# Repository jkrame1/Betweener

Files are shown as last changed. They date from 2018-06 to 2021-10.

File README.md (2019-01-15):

# Betweener
Learn to build and program the Betweener in the wiki: https://github.com/jkrame1/Betweener/wiki

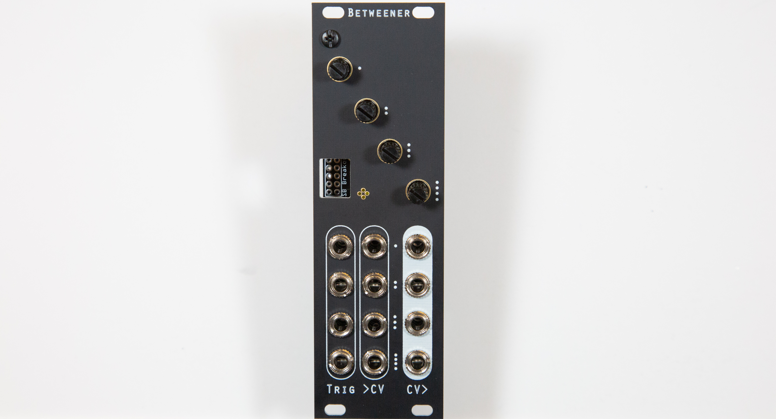
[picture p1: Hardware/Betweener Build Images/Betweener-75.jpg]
Betweener Panel


Description

The Betweener is an affordable, DIY module (Eurorack-compatible) for use in synthesis and multi-instrument systems.  It combines the flexibility of a Teensy 3.2 (programmable using the Arduino IDE) with four built-in Control Voltage (CV) inputs, four Trigger inputs, four knobs, and four CV outputs.  Via USB MIDI or an add-on DIN MIDI breakout, the Betweener enables MIDI-to-CV and CV-to-MIDI conversion in a highly customizable and hackable format.   

The Betweener is envisioned as a programmable platform that expands control capabilities for modular synthesis and MIDI-capable instrument systems and DAWs.  Typically it would not be used as an instrument on its own, but would sit “between” other devices, mediating control messages, converting signals from one format to another, or providing a central “brain” for a complex system.  However, because it is based around the Teensy (retaining the ability to use the associated Teensy Audio Shield), the possible applications are virtually limitless.  

For example, the Betweener can be used to:
- Translate MIDI CC signals (e.g. from a foot pedal) into CV outputs from 0 to 5 volts
- Use external triggers to trigger custom-programmed MIDI note sequences
- Take input from a variety of Teensy-compatible external sensors (e.g. motion sensors, light sensors, etc.) and convert      information into MIDI or CV outputs
- Use programmable knobs to modulate any CV-controlled or MIDI-controlled instrument
- Easily communicate between modular synthesizers and digital audio workstations such as Ableton Live and Reaper

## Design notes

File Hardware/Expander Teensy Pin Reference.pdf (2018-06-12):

Betweener Header Pinouts
Betweener V1.1.0

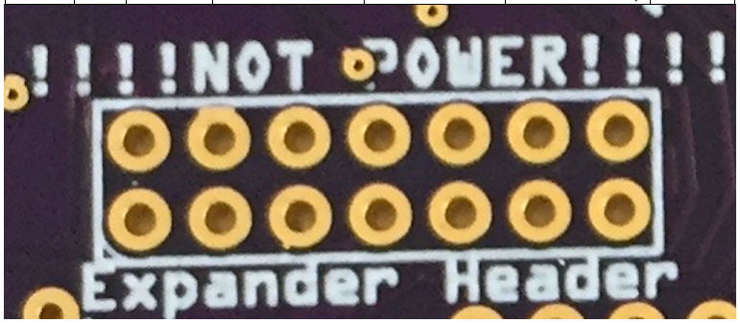
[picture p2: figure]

(bottom end) | I

2C Header
PIN8 GND | PIN7 +5V | PIN6 +3.3V | PIN5 D29/A18 (SCL1)
PIN1 GND | PIN2 +5V | PIN3 +3.3V | PIN4D30/A19 (SDA1)

Expansion Header

PIN14 +3.3V | PIN13 GND | PIN12 D8(LED) | PIN11 D33(touch) | PIN10 D31/A20 (serial2 Tx for DINMIDI) | PIN9 D25(touch)PWM | PIN8 D27/A16
PIN1 +5VNC | PIN2 GND | PIN3 A14/DAC | PIN4 D32(touch)/PWM | PIN5 D24 | PIN6 D26/A15(serial2 Rx for DIN MIDI) | PIN7 D28/A17

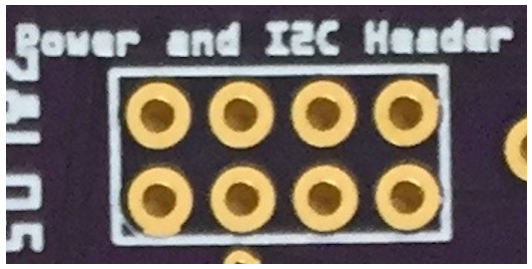
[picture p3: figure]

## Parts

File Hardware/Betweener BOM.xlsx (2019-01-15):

Notes | project part#s | Part Name | Quantity | cost per unit | Total $/qty | Mouser Part Number | DIGIKEY Part Number | Thonk Part Number | OSH Park | Adafruit | McMaster-Carr | PJRC
 |  |  |  |  | 1
 |  | 100Ω | 8 | 0.012 | 0.096 | 603-CFR-25JR-52100R (https://www.mouser.com/ProductDetail/Yageo/CFR-25JR-52-100R?qs=sGAEpiMZZMu61qfTUdNhG46uveXc7ceAq96updtH0Lo%3d)
 |  | 100kΩ | 12 | 0.018 | 0.216 | 270-100K-RC (https://www.mouser.com/Search/ProductDetail.aspx)
 |  | 33kΩ | 4 | 0.13 | 0.52 | 299-33K-RC (https://www.mouser.com/Search/ProductDetail.aspx?R=299-33K-RCvirtualkey21980000virtualkey299-33K-RC)
 |  | 68kΩ | 8 | 0.02 | 0.16 | 588-OJ6835E-R52 (https://www.mouser.com/Search/ProductDetail.aspx)
for LED |  | 220Ω | 1 | 0.1 | 0.1 | 603-CFR-25JR-52220R (https://www.mouser.com/ProductDetail/Yageo/CFR-25JR-52-220R)
 |  | LED | 1 | 0.12 | 0.12 | 859-LTL-4254 (https://www.mouser.com/ProductDetail/Lite-On/LTL-4254)
 |  | 2n2222 or 3904 | 4 | 0.23 | 0.92 | 512-PN2222ATF (https://www.mouser.com/Search/ProductDetail.aspx)
 |  | 14-pin DIP IC socket | 4 | 0.14 | 0.56 | 571-1-2199298-3 (https://www.mouser.com/Search/ProductDetail.aspx)
 |  | 13-pin female header | 2 | 0.88 | 1.76 |  | S7046-ND (https://www.digikey.com/scripts/DkSearch/dksus.dll?Detail&itemSeq=244510705&uq=636487757345609955)
 |  | 7-pin female header | 5 | 0.61 | 3.05 |  | S7040-ND (https://www.digikey.com/scripts/DkSearch/dksus.dll?Detail&itemSeq=244510706&uq=636487757345609955)
 |  | 5-pin female header | 7 | 0.443 | 3.101 |  | S6103-ND (https://www.digikey.com/scripts/DkSearch/dksus.dll?Detail&itemSeq=244510704&uq=636487757345619957)
 |  | 20 position male pin header strips | 2 | 0.46 | 0.92 |  | S1011EC-20-ND (https://www.digikey.com/scripts/DkSearch/dksus.dll?Detail&itemSeq=244510703&uq=636487757345619957)
 |  | 6004 Quad Op Amp | 2 | 0.53 | 1.06 | 579-MCP6004-I/P (https://www.mouser.com/Search/ProductDetail.aspx)
 |  | MCP4922 12-bit dual DAC | 2 | 3.15 | 6.3 | 579-MCP4922-E/P (https://www.mouser.com/Search/ProductDetail.aspx)
 |  | 10kΩ Potentiometer | 4 | 0.78 | 3.12 | 652-PTV09A4020SB104 (https://www.mouser.com/Search/ProductDetail.aspx)
 |  | 1/8” Thonkiconn Jacks with nuts | 12 | 0.46 | 5.52 |  |  | Thonkiconn Jacks (PJ301M-12) (https://www.thonk.co.uk/shop/3-5mm-jacks/)
 |  | Sparkfun Teensy 3.x header kit | 1 | 1.5 | 1.5 | 474-PRT-13925 (https://www.mouser.com/Search/ProductDetail.aspx)
 |  | Teensy 3.2 | 1 | 22.5 | 22.5 | 474-DEV-13736 (https://www.mouser.com/Search/ProductDetail.aspx) |  |  | $17 from OSH Park |  |  | $19.50 directly from PJRC (https://www.pjrc.com/store/teensy32.html)
 |  | Capacitor - .1µF (100nF) | 1 | 0.1 | 0.1 | 594-K104K15X7RF5UH5 (https://www.mouser.com/productdetail/vishay-bc-components/k104k15x7rf5uh5)
 |  | Capacitor - .33µF | 1 | 0.2 | 0.2 | 810-FG18X7R1H334KRT0 (https://www.mouser.com/productdetail/tdk/fg18x7r1h334krt00)
 |  | 78l05 - 5v regulator | 1 | 0.301 | 0.301 | 512-LM78L05ACZ (https://www.mouser.com/productdetail/on-semiconductor-fairchild/lm78l05acz?qs=sGAEpiMZZMtdAabcSkQOl9gipZmsKLz7)
 |  | shorting jumper | 1 | 0.11 | 0.11 |  | S9341-ND (https://www.digikey.com/product-detail/en/sullins-connector-solutions/NPC02SXON-RC/S9341-ND/2618266)
Optional |  | MicroUSB B breakout (Adafruit) | 1 | 1.35 | 1.35 | 485-1833 (https://www.mouser.com/ProductDetail/Adafruit/1833) |  |  |  | https://www.adafruit.com/product/1833
needed for front-plate USB Breakout |  | 5-pin right-angle male header | 1 |  |  |  | #VALUE! (https://www.digikey.com/products/en/connectors-interconnects/rectangular-connectors-headers-male-pins/314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)
 |  | rainbow ribbon cable?
 |  | 10mm M3 male-female standoff | 2 | 0.54 | 1.08 | 855-R30-3001002 (https://www.mouser.com/ProductDetail/Harwin/R30-3001002) |  |  |  |  | https://www.mcmaster.com/#93655A102
 |  | M3 Screws | 5 | 0.21 | 1.05 | 534-9191-3 (https://www.mouser.com/ProductDetail/Keystone-Electronics/9191-3)
can't find on Mouser |  | M3 nut | 1
 |  | TOTAL |  |  | 55.714
 |  | Total PER UNIT (excluding PCB) |  |  | 55.714
PCB PRICES FROM OSHPARK
 |  | DAC PCB | 1 | 6.5 | 6.5 |  |  |  | Order from OSH Park
 |  | Interface PCB | 1 | 6.5 | 6.5 |  |  |  | Order from OSH Park

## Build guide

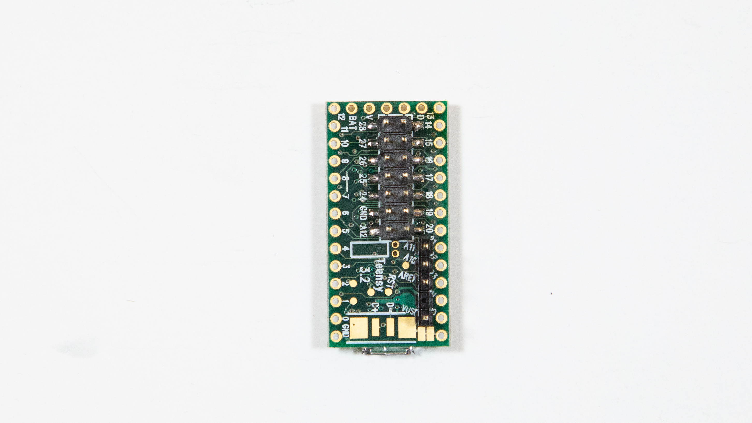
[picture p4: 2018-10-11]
Hardware/Betweener Build Images/Betweener-44.jpg

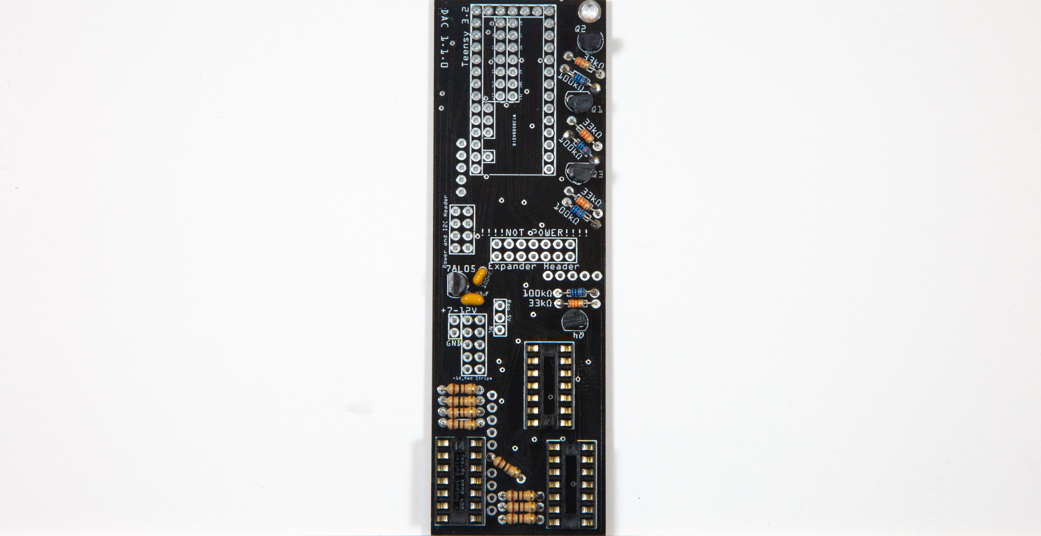
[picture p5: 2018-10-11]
Hardware/Betweener Build Images/Betweener-16.jpg

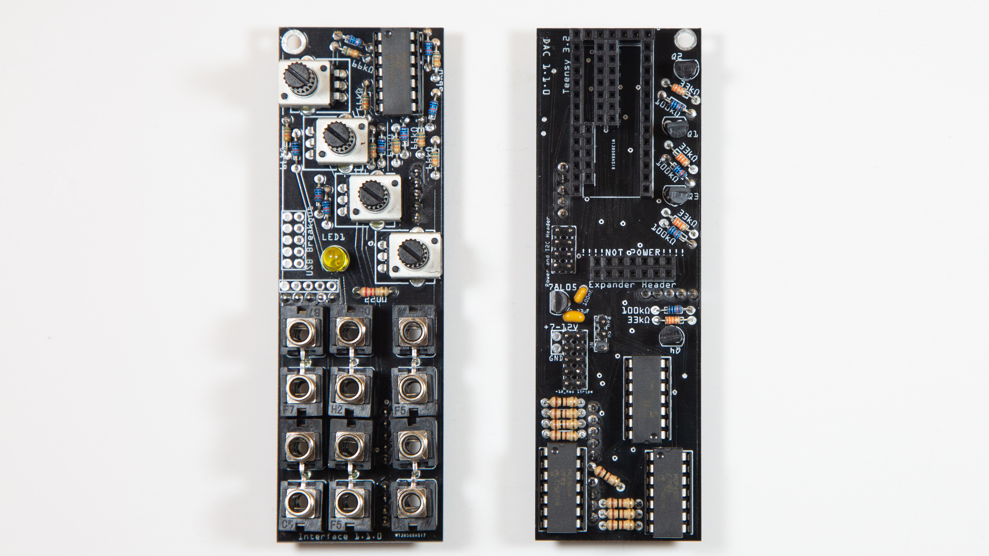
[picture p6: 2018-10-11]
Hardware/Betweener Build Images/Betweener-35.jpg

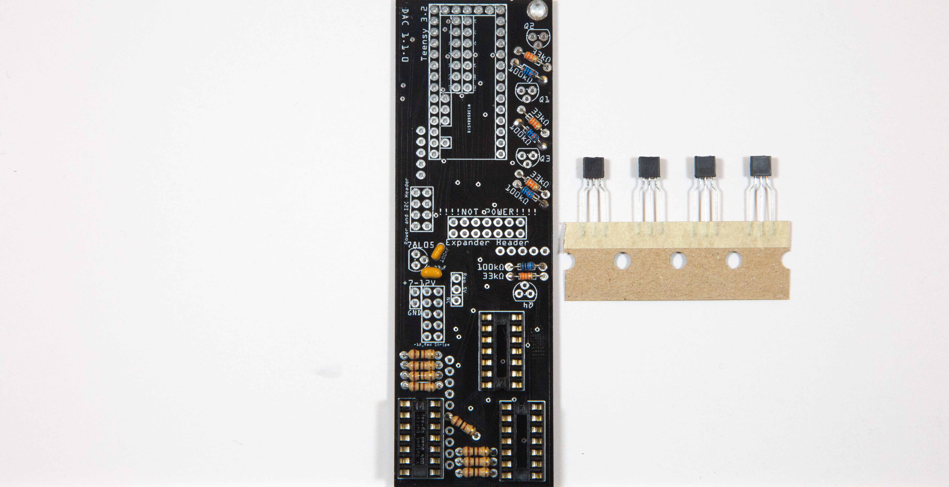
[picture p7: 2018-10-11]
Hardware/Betweener Build Images/Betweener-13.jpg

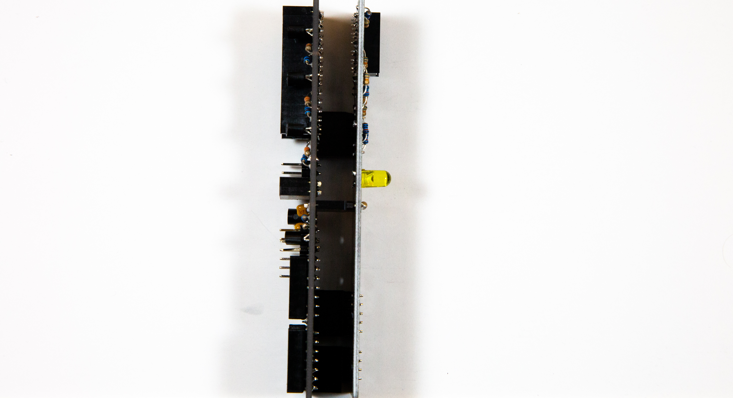
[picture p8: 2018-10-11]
Hardware/Betweener Build Images/Betweener-28.jpg

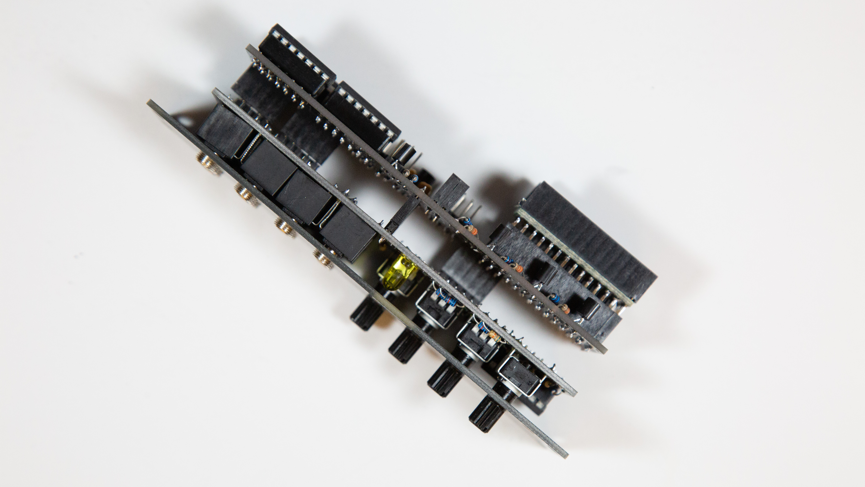
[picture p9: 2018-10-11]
Hardware/Betweener Build Images/Betweener-53.jpg

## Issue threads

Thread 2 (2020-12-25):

MIDI library v5.0 and above

jamescaf, 2020-12-25:
Hello,
Thanks for making this such an easy and well-documented build and installation. I noticed that the Teensyduino Betweener library wouldn't work with the MIDI library v5.0 and above (I neglected to copy the error messages, my apologies, but they seemed to center around the endTransmission() lines and similar in the Betweener library). If I manually installed MIDI library v4.3.1, the example Arduino sketches worked perfectly. Thanks again!

jkrame1, 2020-12-26:
Hello James,
Thanks so much for the note. I have a guess about the cause of this and will look into ASAP. Thanks again.

jamescaf, 2021-11-21:
Great, thanks!

Closed 2021-11-21.

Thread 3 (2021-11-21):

Question about reprogramming when powering from Eurorack power supply

jamescaf, 2021-11-21:
Hello,
Feel free to delete or close if this is outside the scope for github issues. If I have the USB breakout connected to the front panel, and I cut the trace on the teensy and set the power jumper to use the 5V regulator in order to power the unit in my eurorack case, will I still be able to reprogram my teensy using the USB connector on the front panel while powering it from a eurorack power supply? Thanks!

jkrame1, 2021-11-21:
Hello @jamescaf! Yes! The same data lines that carry the MIDI are used for programming and reprogramming. So if the front panel breakout is wired correctly for MIDI then it is wired correctly for programming regardless of how the Teensy is getting powered.

jamescaf, 2021-11-21:
Awesome, thanks!

Closed 2021-11-21.

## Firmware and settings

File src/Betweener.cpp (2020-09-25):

//
//  Betweener.cpp
//
//  Copyright (c) 2018 Kathryn Schaffer

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
///////////////////////////////////////////////////////////////////////////////
//  Betweener.cpp detailed description:
//
//  This is the "implementation file" for the Betweener library.  Most of the
//  important overall comments about this library are in the associated
//  header file (Betweener.h).  This file is also obsessively commented, though,
//  with novice users in mind.
////////////////////////////////////////////////////////////////////////////////

//the functions and many variables in this file were all
//declared in Betweener.h, so we include it
#include "Betweener.h"

//Now, below, we have the code implementing all the functions
//(a.k.a. methods) of the Betweener class.
//The Betweener:: syntax specifies to the compiler that these
//functions live in the "Betweener namespace" which means that
//they will not conflict with other functions associated with
//other classes that have similar names.

Betweener::Betweener(void){
    //Constructor.  This code is run when you make a Betweener object.
    //We do not actually do much in this constructor.  For technical reasons
    //it is better to put all of the important stuff in a begin() function.
    
    //so... we just initialize some internal variables to nonsense values
    //so that they are not uninitialized.
    currentCV1=-1;
    currentCV2=-1;
    currentCV3=-1;
    currentCV4=-1;
    
    currentKnob1=-1;
    currentKnob2=-1;
    currentKnob3=-1;
    currentKnob4=-1;

    lastCV1=-1;
    lastCV2=-1;
    lastCV3=-1;
    lastCV4=-1;
    
    lastKnob1=-1;
    lastKnob2=-1;
    lastKnob3=-1;
    lastKnob4=-1;
    
}
    

void Betweener::begin(void){
    //this does all the real setup stuff
    
    //Note that all of the upper-case "variables" here are actually
    //defined in preprocessor directives in the .h file.
    //They cannot be modified at run time.
    
    //These are the settings needed to get the SPI working
    //for the DACs to create CV out
    pinMode(DAC_CHIP_SELECT1, OUTPUT);
    digitalWrite(DAC_CHIP_SELECT1, HIGH);
    pinMode(DAC_CHIP_SELECT2, OUTPUT);
    digitalWrite(DAC_CHIP_SELECT2, HIGH);
   
    //Start SPI
    //note that the order here is important when using the Audio shield
    SPI.setMOSI(SPI_MOSI);  //use alternate SPI MOSI
    SPI.setSCK(SPI_SCK);  //use alternate SPI SCK
    SPI.begin();
 
    
    //Here, we tell Teensy what to do with trigger pins
    pinMode(TRIGGER_INPUT1, INPUT_PULLUP);
    pinMode(TRIGGER_INPUT2, INPUT_PULLUP);
    pinMode(TRIGGER_INPUT3, INPUT_PULLUP);
    pinMode(TRIGGER_INPUT4, INPUT_PULLUP);
  
    
    // Create Bounce objects for each button.  The Bounce object
    // automatically deals with contact chatter or "bounce", and
    // it makes detecting changes very simple.
        // Note that bounce_ms is set to a default in the .h file
    trig1.attach(TRIGGER_INPUT1);
    trig1.interval(bounce_ms);
    
    trig2.attach(TRIGGER_INPUT2);
    trig2.interval(bounce_ms);
    
    trig3.attach(TRIGGER_INPUT3);
    trig3.interval(bounce_ms);
    
    trig4.attach(TRIGGER_INPUT4);
    trig4.interval(bounce_ms);
 

    //set up the smoothed analog readout objects
    //this depends on our own modified version of the
    //responsiveAnalogRead library
    smoothCV1.begin(CVIN1, RASleep, RASnapMultiplier);
    smoothCV1.setActivityThreshold(RAActivityThreshold);
    
    smoothCV2.begin(CVIN2, RASleep, RASnapMultiplier);
    smoothCV2.setActivityThreshold(RAActivityThreshold);
    
    smoothCV3.begin(CVIN3, RASleep, RASnapMultiplier);
    smoothCV3.setActivityThreshold(RAActivityThreshold);
    
    smoothCV4.begin(CVIN4, RASleep, RASnapMultiplier);
    smoothCV4.setActivityThreshold(RAActivityThreshold);
    
    smoothKnob1.begin(KNOB1, RASleep, RASnapMultiplier);
    smoothKnob1.setActivityThreshold(RAActivityThreshold);
  
    smoothKnob2.begin(KNOB2, RASleep, RASnapMultiplier);
    smoothKnob2.setActivityThreshold(RAActivityThreshold);
    
    smoothKnob3.begin(KNOB3, RASleep, RASnapMultiplier);
    smoothKnob3.setActivityThreshold(RAActivityThreshold);
    
    smoothKnob4.begin(KNOB4, RASleep, RASnapMultiplier);
    smoothKnob4.setActivityThreshold(RAActivityThreshold);
  
    
    //If we are using DIN MIDI I/O we need some setup:
#ifdef DODINMIDI
    Serial2.setRX(DINMIDIIN);
    Serial2.setTX(DINMIDIOUT);
    DINMIDI.begin(MIDI_CHANNEL_OMNI);  //monitor all input channels
#endif
    
}


void Betweener::readTriggers(void){
    //The bounce library has a function update() that is the
    //main read function
    trig1.update();
    trig2.update();
    trig3.update();
    trig4.update();
    
}


void Betweener::readCVs(void){
    //we could put stuff in here to limit the read
    //rate, but right now we'll leave that to the sketch
    
    lastCV1 = currentCV1;
    lastCV2 = currentCV2;
    lastCV3 = currentCV3;
    lastCV4 = currentCV4;
    
    smoothCV1.update();
    smoothCV2.update();
    smoothCV3.update();
    smoothCV4.update();
  
    currentCV1 = smoothCV1.getValue();
    currentCV2 = smoothCV2.getValue();
    currentCV3 = smoothCV3.getValue();
    currentCV4 = smoothCV4.getValue();
    

}


void Betweener::readKnobs(void){
 
    lastKnob1=currentKnob1;
    lastKnob2=currentKnob2;
    lastKnob3=currentKnob3;
    lastKnob4=currentKnob4;

    smoothKnob1.update();
    smoothKnob2.update();
    smoothKnob3.update();
    smoothKnob4.update();
    
    currentKnob1=smoothKnob1.getValue();
    currentKnob2=smoothKnob2.getValue();
    currentKnob3=smoothKnob3.getValue();
    currentKnob4=smoothKnob4.getValue();
    
}

void Betweener::readUsbMIDI(void) {
    //with each read, the usbMidi object
    //will store whatever messages it most recently received
    usbMIDI.read();
    
}


#ifdef DODINMIDI
void Betweener::readDINMIDI(void){
        DINMIDI.read();
}
#endif


void Betweener::readAllInputs(void){
    //run the previous four functions all in sequence
    readTriggers();
    readCVs();
    readKnobs();
    readUsbMIDI();
#ifdef DODINMIDI
    readDINMIDI();
#endif
}
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

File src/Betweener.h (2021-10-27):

//
//  Betweener.h
//
//  Copyright (c) 2018 Kathryn Schaffer
 
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
///////////////////////////////////////////////////////////////////////////
//  Betweener.h detailed description:
//  
//  This .h file defines the Betweener class, setting up all the
//  variables and providing the "function prototypes" that tell the
//  compiler what functions the class contains.  The associated .cpp file has
//  the implementation (the actual code) for all the functions.
//
//  The purpose of the Betweener class is to set up the software mappings
//  that enable Teensy to communicate via the soldered-together connections
//  on the Betweener device itself.
//
//  The Betweener class also includes functions that allow a
//  slightly streamlined set of read/write operations so that the
//  device can mediate between CV inputs and outputs, MIDI inputs and
//  outputs, and trigger inputs.
//
//  The class has been written assuming it will be read and modified
//  by users with little coding experience, and is thus obsessively
//  commented with that audience in mind.
//
//  To test the Betweener hardware and see examples of how to use this
//  library, load and run the sketch betweener_hardware_tests.ino
//
//  ADDITIONAL CREDITS:
//      Betweener hardware design: Joseph Kramer
//      This code uses code snippets from:
//          Sebastian Tomczak (MCP4922 write function)
//
//////////////////////////////////////////////////////////////////////////

//these statements are a standard C++ way to avoid accidentally
//re-loading this .h file multiple times, which can make for weird
//conflicts in parameter and function definitions in certain cases
#ifndef Betweener_h
#define Betweener_h


//Here is where we include all the other Arduino libraries that this
//depends on.  We're using the updated "Bounce2" library because it
//is more compatible with being used in other libraries
#include <Arduino.h>
#include <SPI.h>
#include <Bounce2.h>
#include <MIDI.h>
#include <ResponsiveAnalogRead.h>


//This is where we define hard-wired pin associations.
//These are "preprocessor directive" statements (with # symbol) instead of
//variable definitions.  We use uppercase names in order to make it
//easy to tell that these are not normal variables when we invoke them in the
//code.  The difference is that #define statements are only implemented when
//the code is compiled, and never when the code is just being run.
//That makes it impossible for any of the code to actively change these
//parameters while it is running, which is a good idea since the
//definitions relate to hard-wired configuration choices.

//SPI is a communication protocol used for the digital-analog-converters (DACs)
//in the device.  These are used to create the CV outputs.
//SPI communication requires two pins for special functions,
//called MOSI and SCK.
#define SPI_MOSI 7 // note this is technically the "alternate" MOSI option for Teensy
#define SPI_SCK 14
//Also for the SPI protocol, these parameters are used to select
//which DAC we are sending messages to
#define DAC_CHIP_SELECT1 1
#define DAC_CHIP_SELECT2 2
//Identify the 4 CV outs with the right chip and DAC.
//This is something that may change for different board versions.
#define CVOUT1_CHIP_SELECT 2
#define CVOUT1_DAC_CHANNEL 1
#define CVOUT2_CHIP_SELECT 1
#define CVOUT2_DAC_CHANNEL 0
#define CVOUT3_CHIP_SELECT 2
#define CVOUT3_DAC_CHANNEL 0
#define CVOUT4_CHIP_SELECT 1
#define CVOUT4_DAC_CHANNEL 1

//Other pins used for inputs (which may change for different board versions)
//digital pins used for trigger inputs
#define TRIGGER_INPUT1 0
#define TRIGGER_INPUT2 3
#define TRIGGER_INPUT3 5
#define TRIGGER_INPUT4 4
//analog inputs used for the 4 CV inputs
#define CVIN1 A7
#define CVIN2 A6
#define CVIN3 A3
#define CVIN4 A2
//analog inputs used for the 4 potentiometers/knobs
#define KNOB1 A12
#define KNOB2 A13
#define KNOB3 A11
#define KNOB4 A10


//use this flag to decide whether to make use of DIN midi or not
//If you want it, uncomment the line in the code that says #define DODINMIDI.
//Otherwise, leave it commented it out.
//Note that if you use MIDI DIN, you will need
//the updated MIDI library for Teensy, from here:
//https://github.com/FortySevenEffects/arduino_midi_library
//and you will need to delete the default MIDI.h file that
//is included in the Arduino package.
//#define DODINMIDI


//If we do choose to use hardware MIDI, these will be
//the pins.  Alternate pins for Serial2.  See:
//https://www.pjrc.com/teensy/td_uart.html
#define DINMIDIIN 26
#define DINMIDIOUT 31


//If you want the code to give you some error messages in the
//serial monitor, leave the line below. Otherwise, comment it out.
#define DEBUG  //leave this line in to have automatic error printouts to Serial monitor
//this little "preprocessor macro" (which is like a function but processed at a different time)
//will be used to print the debug info.  See examples in the .cpp file for how this gets used.
#ifdef DEBUG
#define DEBUG_PRINT(...) Serial.print(__VA_ARGS__)
#define DEBUG_PRINTLN(...) Serial.println(__VA_ARGS__)
#else
#define DEBUG_PRINT(...)
#define DEBUG_PRINTLN(...)
#endif


//////////////////////////////////////////////////////////////////////////////
//Now we define the Betweener class, which will let us make Betweener objects
//in our sketches.  The class organizes a set of functions (called "methods") and
//the set of variables that they use and control.  A special method called the
//"constructor" is the one that initially builds the object and puts in all the
//default variable definitions.  The other methods provide a flexible interface
//for defining how the Betweener maps inputs to outputs and for controlling
//its read/write operations and other operations.
//
//All variables and all methods get declared in this .h file, but the actual
//code for the functions themselves lives in the .cpp file, not here.  The
//.h file does have some core definitions of defaults for some variables, but
//mostly it exists to tell the compiler how much space to allocate when
//building a Betweener object, and what kinds of structures to expect the
//Betweener objects to contain.  The compiler then looks in the .cpp file to
//fill in the details of the actual functions/code.
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

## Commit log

2018-06-12 changed a name for arduino convention
2018-06-12 PCB Files
    [Betweener BOM.xlsx, DAC 1.1.0.fzz, Interface 1.1.0.fzz]
2018-06-12 Breakout Header Teensy Pin Connections
2018-06-12 Eurorack Panel Layout for Laser Cutter
2018-06-12 Breakout Header Teensy Pin Numbers and Functions
2018-06-17 Updated schematics to include CC-BY-SA License notice
    [DAC 1.1.0.fzz, DAC 1.1.1.fzz, Interface 1.1.0.fzz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]
2018-06-17 updated to include license info
    [Interface 1.1.1.fzz]
2018-06-20 Updated to fix gate behavior
    [D2_USB_MIDI_Note_to_NoteCV.ino]
2018-08-07 new demo sketch for four LFOs with fixed frequency relationships
    [Quad_LFO_Demo.ino]
2018-08-22 Updates to the BOM
    Included missing power components
    [Betweener BOM.xlsx]
2018-08-24 inital commit of new Envelope Generator example program sketch
    Crude misuse of Teensy Audio Library Objects to create control-rate messages for the Betweener's CV outputs.
2018-09-25 updated titles for angry arduino
2018-11-28 Updated BOM to include shorting jumper
    [Betweener BOM.xlsx]
2018-12-17 Trial Reorganization
    [Betweener BOM.xlsx, DAC 1.1.1.fzz, Interface 1.1.1.fzz]
2019-01-15 Updated BOM
    [Betweener BOM.xlsx]
2019-03-29 Added Sample conversion program
    new conversion example uses NoteSet Library, found here: https://github.com/kschaffer/NoteSet
2020-09-24 Fixing small documentation typos
    [Betweener.cpp, Betweener.h]
2021-10-27 Turn DIN MIDI OFF by default
    this is a temporary fix to allow all functions of the library to work except DIN MIDI while the library waits for an update to fix this broken function.
    [Betweener.h]
